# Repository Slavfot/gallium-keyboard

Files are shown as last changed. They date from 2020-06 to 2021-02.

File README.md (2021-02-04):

## Gallium Keyboard

The Gallium Keyboard is a Wireless Ergonomical Split Keyboard.

# DISCLAIMER

I have a problem with the keyboard that i have opened an issue at the redox Github. https://github.com/mattdibi/redox-keyboard/issues/55
The problem is interference making it hard to use in some environments.
I use it daily at work and it works really good except sometimes i have to replug the usb receiver at startup to get a good connection.
At home it is almost unusable because of interference. Missing key presses and high latency.
I'm trying to solve this and will post an update when i find a stable solution for the wireless communication.

# Future
At the moment I'm working on a micro pro version wich will make it possible to use the nice!nano bluetooth module with it instead.
My goal is to stock these and sell as kits togehter with 3D printed case. And even aluminium cases in GB.

## Summary

  - [Bill of materials](#bill-of-materials)
  - [Transmitters Assembly](#transmitters-assembly)
  - [Receiver Assembly](#receiver-assembly)
  - [Firmware](#firmware)
  - [Battery usage](#battery-usage)

## Bill of materials

#### Transmitters

| Qty | Item | Notes |
|----:|---|---|
|  62 | Cherry MX compatible switches | |
|  62 | Kailh MX hot swap sockets (optional) | |
| 2 | Gallium Wireless PCBs | |
| 2 | YJ-14015 modules (Core51822B clones) | [aliexpress or ebay](https://www.aliexpress.com/item/NRF51822-Core51822-BLE-4-0-Bluetooth-2-4G-Wireless-Module-Antenna-Board-For-ULP-SPI-I2C/32842154172.html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,searchweb201602_1_10065_10068_10843_10059_10884_10887_10696_100031_10084_10083_10103_10618_10304_10307_10820_10821_10302,searchweb201603_60,ppcSwitch_5&algo_expid=1dded059-5054-4890-bcc4-6face1150a21-1&algo_pvid=1dded059-5054-4890-bcc4-6face1150a21&priceBeautifyAB=0)
|  62 | 1N4148 diodes | SMD 1N4148 SOD-123 diodes can also be used |
| 2 | Keystone 3034 SMT battery holders | [digikey](https://www.digikey.com/product-detail/en/keystone-electronics/3034/36-3034-ND/4499289)|
| 2 | PCM12SMTR SMT slide switches | [digikey](https://www.digikey.com/product-detail/en/c-k/PCM12SMTR/401-2016-1-ND/1640125)|
| 2 | Right angle 0.1" header (1x4pin) | |

#### Receiver

| Qty | Item | Notes |
|----:|---|---|
| 1 | Redox receiver PCB | |
| 1 | YJ-14015 module (Core51822B clone) | [aliexpress or ebay](https://www.aliexpress.com/item/NRF51822-Core51822-BLE-4-0-Bluetooth-2-4G-Wireless-Module-Antenna-Board-For-ULP-SPI-I2C/32842154172.html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,searchweb201602_1_10065_10068_10843_10059_10884_10887_10696_100031_10084_10083_10103_10618_10304_10307_10820_10821_10302,searchweb201603_60,ppcSwitch_5&algo_expid=1dded059-5054-4890-bcc4-6face1150a21-1&algo_pvid=1dded059-5054-4890-bcc4-6face1150a21&priceBeautifyAB=0) |
| 1 | Arduino 5v 16MHz Pro Micro compatible microcontroller  | [aliexpress or ebay] |
| 1 | 1117 3.3v regulator in SOT223 | [digikey](https://www.digikey.com/product-detail/en/diodes-incorporated/AZ1117IH-3.3TRG1/AZ1117IH-3.3TRG1DICT-ND/5699682)|
| 2 | 330 Ohm 0805(2012 metric) SMD resistors | Default configuration. Values depends on LED color, see [below](#resistor-values)|
| 2 | 220 Ohm 0805(2012 metric) SMD resistors | Default configuration. Values depends on LED color, see [below](#resistor-values)|
| 3 | 1.5k Ohm 0805(2012 metric) SMD resistors | Default configuration. See [below](#resistor-values)|
| 1 | Red 0805(2012 metric) SMD standard LED | Default configuration. |
| 1 | Blue 0805(2012 metric) SMD standard LED | Default configuration. |
| 1 | Green 0805(2012 metric) SMD standard LED | Default configuration. |
| 1 | White 0805(2012 metric) SMD standard LED | Default configuration. |
| 1 | Through hole momentary switch | Dimensions 6mm x 6mm x 4.3mm |
| 1 | Right angle 0.1" header (1x4pin) | |
| 2 | Straight hot swap 0.1" header (1x6pin) | Use wire from diods as legs |

> :information_source: You can also use the [Mitosis receiver](https://github.com/reversebias/mitosis-hardware/blob/master/bom/README.md) since it's almost identical, or you can build a receiver on your own. 

> :warning: To program the YJ-14015 MCUs you need an ST-Link v2 programmer, these can be found on eBay or Aliexpress for as little as 2$ shipped. See [picture below](#nordic-mcus-firmware).

##### Resistor values

If you want to customize your LEDs color or save a few bucks by ordering the LED all the same color you can refer to this section for choosing the correct resistor values. Otherwise you can refer to the [default configuration](#default-configuration).

There are two sets of resistor that you need for the receiver.

- The voltage divider resistors (`R1`, `R2` and `R3`): anything between 1.5k Ohm and 4.7k Ohm is good.
- The LEDs resistors (`R4`,`R6`,`R7` and `R8`): see the following table.

| LED color | Vf | Suggested resistor value |
|---|---|---|
| Red | 1.7V | 330 Ohm |
| Yellow | 2.1V | 330 Ohm |
| Blue | 3.2V | 220 Ohm |
| Green | 2.2V | 330 Ohm |
| White | 3.6V | 220 Ohm |

Depending on the color you choose to use you should use the resistor listed above.

#### Default configuration

Here you can find the default configuration for the receiver assembly.

| Label | Component |
|---|---|
| D1 | Red LED |
| D2 | Blue LED |
| D3 | Green LED |
| D4 | White LED |
| R4 |  330 Ohm resistor |
| R6 |  220 Ohm resistor |
| R7 |  330 Ohm resistor |
| R8 |  220 Ohm resistor |
| R1 | 1.5k Ohm resistor |
| R2 | 1.5k Ohm resistor |
| R3 | 1.5k Ohm resistor |

## Transmitters Assembly

<p align="center">
Wireless gallium PCBs
</p>

Assembly steps:

- Solder components to PCBs.
  1. Solder slider switch. 
  2. Solder the YJ-14015 on the same side as the slider switch.
  3. Solder 1N4148 diodes either SMT or THT (Surface-mount Technology or Through-hole Technology).
  4. Apply insulating tape over the pads surrounding the battery ground pad before soldering the battery holder [picture below](#battery-holder-installation-detail).
  5. Some solder is needed on the ground pad to contact properly with the battery. See [picture below](#battery-holder-installation-detail).
  6. Solder the battery holders.
  7. If you use the onboard CR2032 battery holder then bridge the jumper JP_BAT1 to either R or L depending on wich side the battery is located on. See [picture below](#bridge-jumper).
     (This is not needed if you use external battery pinout EXT-BAT)
  8. Solder the programming headers.
  9. (Optional) Solder Kailh Hot Swap Sockets
- Fit the PCBs inside their cases.
- Add the switches to the plate.
- Solder switches to the PCB.
- Add the CR2032 batteries.
- Program the MCUs.
- Close the case.

##### How i solder surface mount components:
Wet one pad with solder.
Position the component and hold the component in place with a tweezer.
Heat up the wet pad and let cool, this should fix the component.
Re-heat and adjust the position if the component isn't placed perfect.
Be sure not to heat to long wich may damage the PCB or the component.
Solder the rest of the pads like normal.

##### Programming headers detail:

<p align="center">
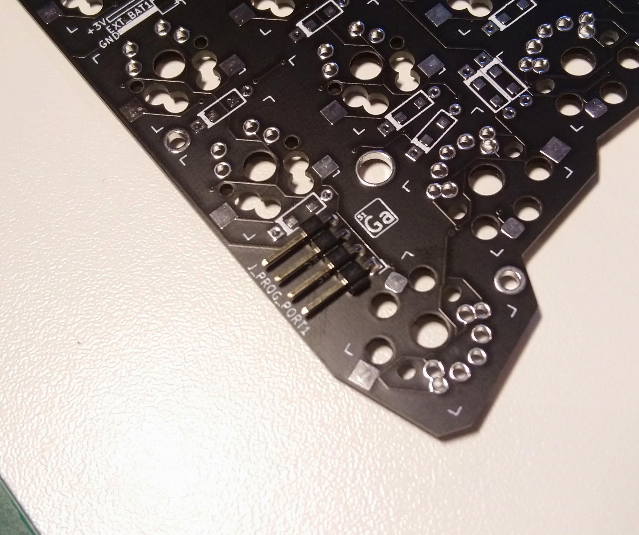
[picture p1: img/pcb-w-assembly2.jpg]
Programming headers detail

</p>

##### MCUs detail:

<p align="center">
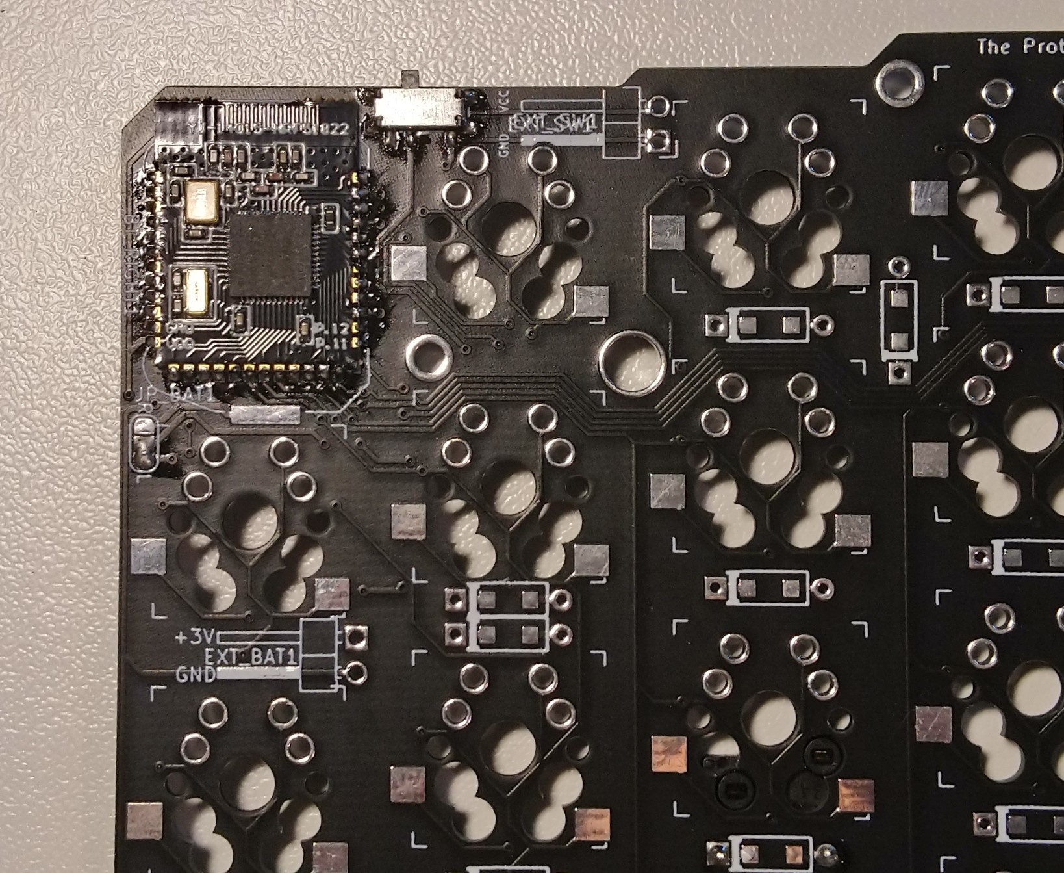
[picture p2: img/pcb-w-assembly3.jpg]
MCUs detail

</p>

##### Slider switch detail:

<p align="center">
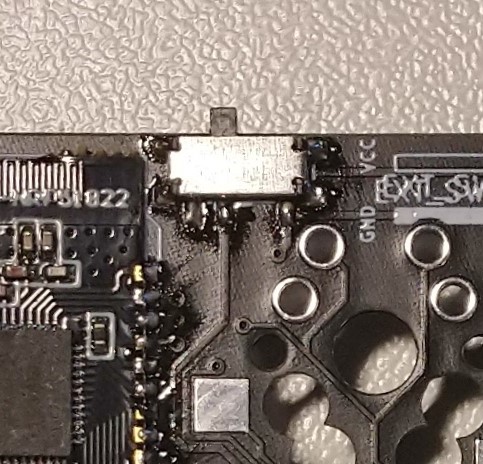
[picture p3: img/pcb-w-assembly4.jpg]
Slider switch detail

</p>

##### Diodes installation detail:

<p align="center">
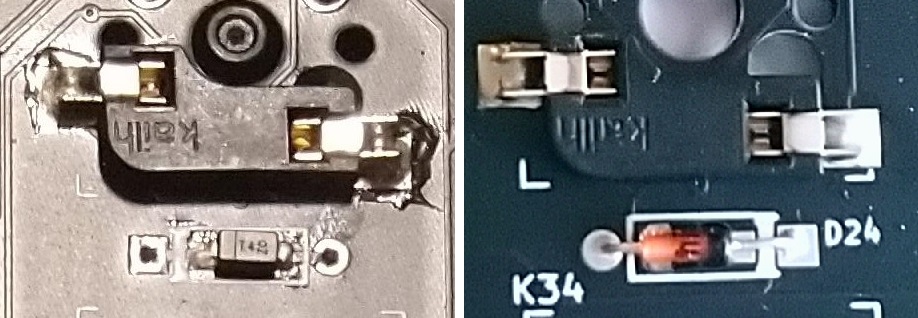
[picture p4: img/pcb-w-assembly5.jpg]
Diode installation detail

</p>
SMT on the left and THT on the right.

##### Battery holder installation detail:

<p align="center">
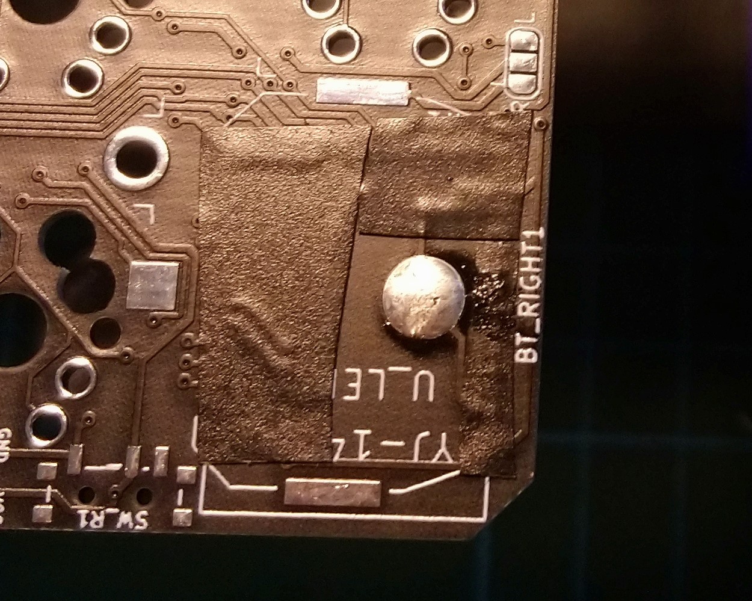
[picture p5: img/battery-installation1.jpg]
Battery holder installation detail. Ground pad.

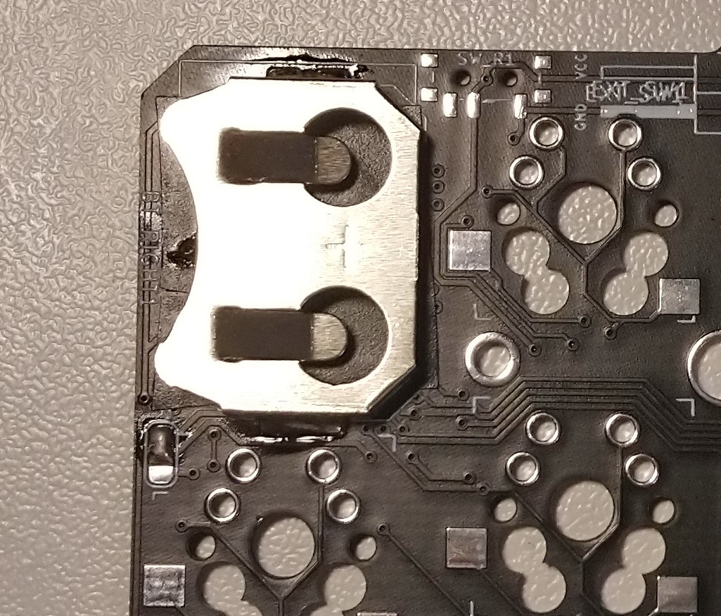
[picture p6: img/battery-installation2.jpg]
Battery holder installation detail. Assembled.

</p>

##### Left and right hand completed assembly:

<p align="center">
Left and right hand completed assembly
</p>

##### Assembled PCB:

<p align="center">
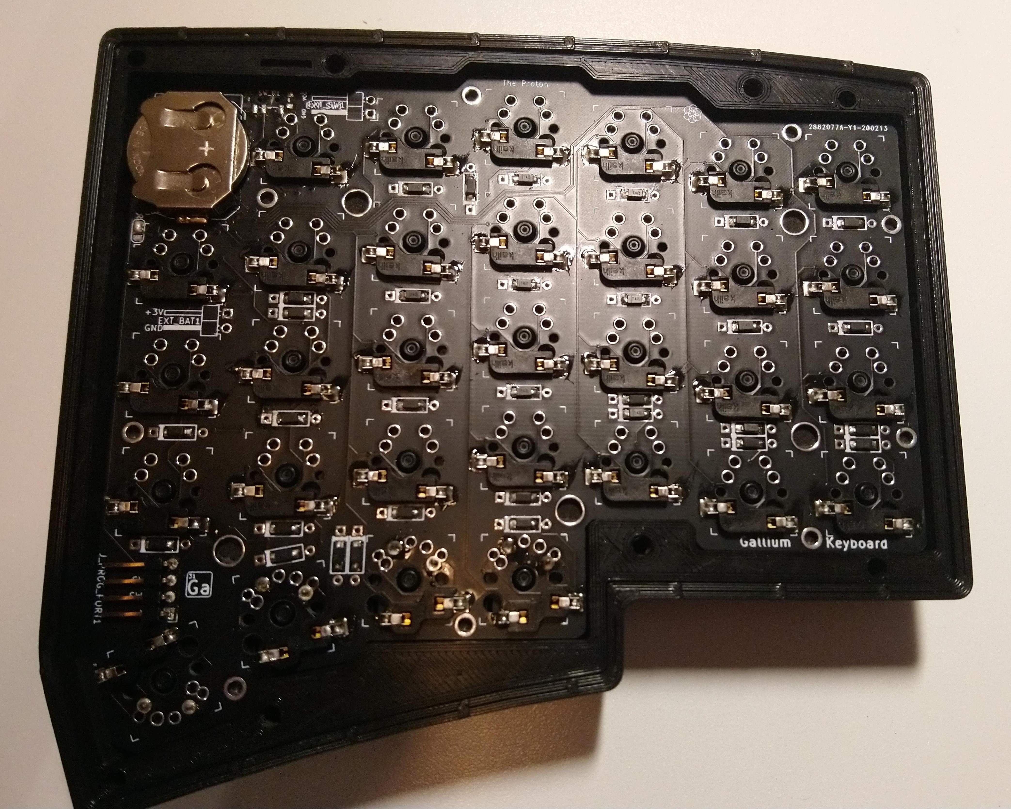
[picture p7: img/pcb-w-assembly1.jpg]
Wireless Redox assembled PCB

</p>

## Receiver Assembly

The receiver assembly is pretty straightforward i suggest soldering it in this order:

1. Solder D1, D2, D3 and D4 LEDs. See [image](#leds-installation-detail) for orientation.
2. Solder R4, R6, R7 and R8 resistors.
3. Solder R1, R2 and R3 resistors.
4. Solder the AMS1117.
5. Solder the programming headers. I suggest you to cut the excess of the header **before** soldering the headers. You should stay as flush to the PCB surface as possible since the controller will be soldered above the headers. Use some masking tape to help you keep the header in place while soldering.
6. Solder the Arduino Pro Micro headers.
7. Solder the YJ-14015. I suggest you to glue it in place or use some masking tape to help you during soldering.
8. Solder the reset button.
9. Upload the firmware and you're done.

##### Assembled PCB, front:

<p align="center">
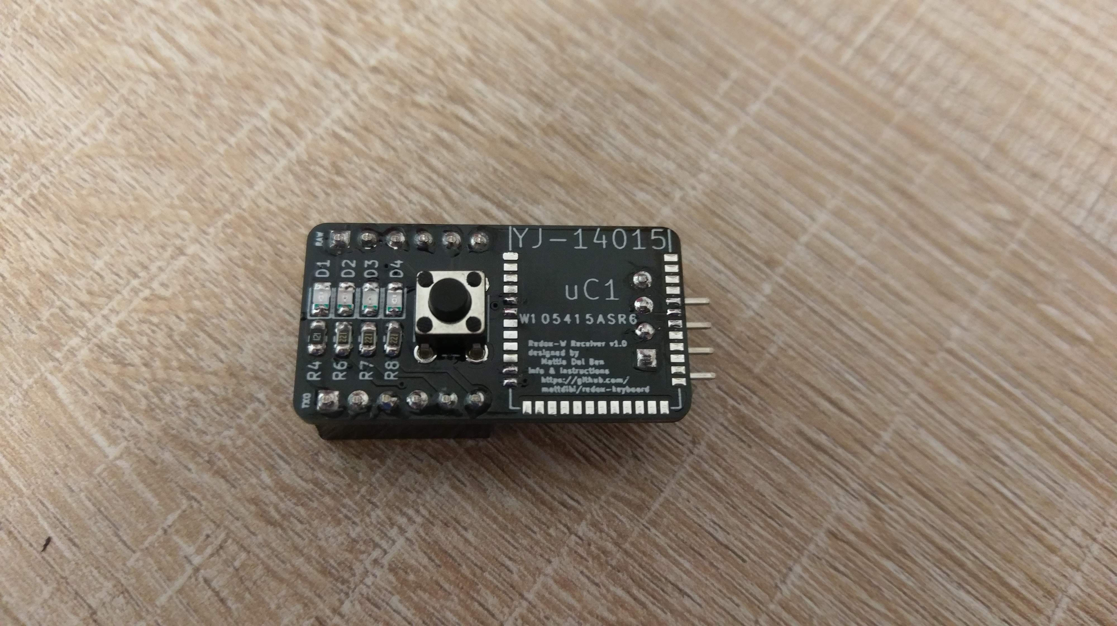
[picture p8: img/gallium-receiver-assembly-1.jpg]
Assembled receiver PCB, front.

</p>

##### Assembled PCB, back:

<p align="center">
Assembled receiver PCB, back.
</p>

##### LEDs installation detail:

<p align="center">
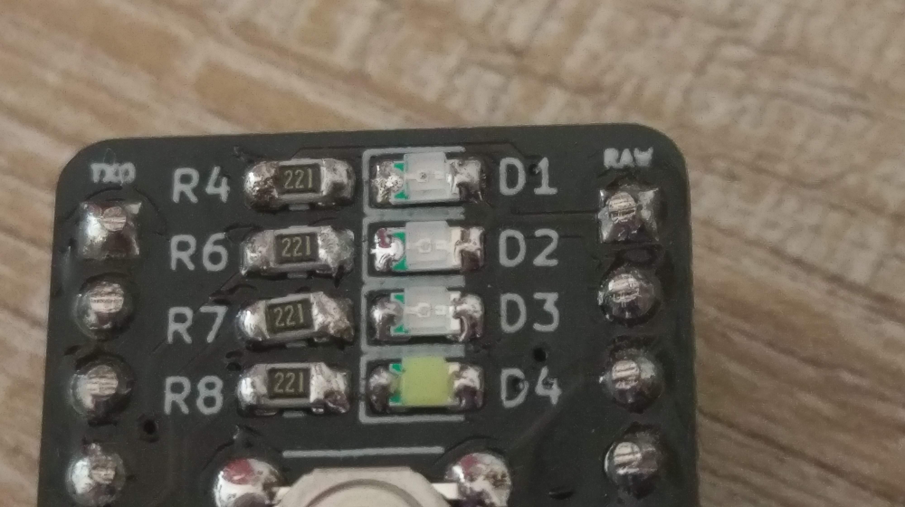
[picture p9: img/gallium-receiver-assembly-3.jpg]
Assembled receiver PCB, LEDs installation detail.

</p>

> :information_source: Please note that here I installed 220 Ohm resistors because I used only blue and white LEDs as I only had those laying around. You should use the resistor values suggested [here](#resistor-values) or follow the [default configuration](#default-configuration).

## Firmware

**Basics**: The Gallium keyboard works similarly to the [Mitosis keyboard](https://github.com/qmk/qmk_firmware/tree/master/keyboards/mitosis): we have two transmitters responsible for scanning the two matrices, which then transmit the matrix status through the [Gazel protocol](https://developer.nordicsemi.com/nRF5_SDK/nRF51_SDK_v5.x.x/doc/5.2.0/html/a00140.html) to the receiver. The receiver is another YJ-14015 which receives the two matrix scans and send it through serial to the Arduino Pro Micro. The Pro Micro is responsible for running QMK and converting the bytes received by the YJ-14015 into actual keystrokes.

Firmware sources available here: [https://github.com/slavfot/gallium-firmware](https://github.com/slavfot/gallium-firmware).

You'll need to upload the firmware to the corresponding MCUs as per the following diagram:

<p align="center">
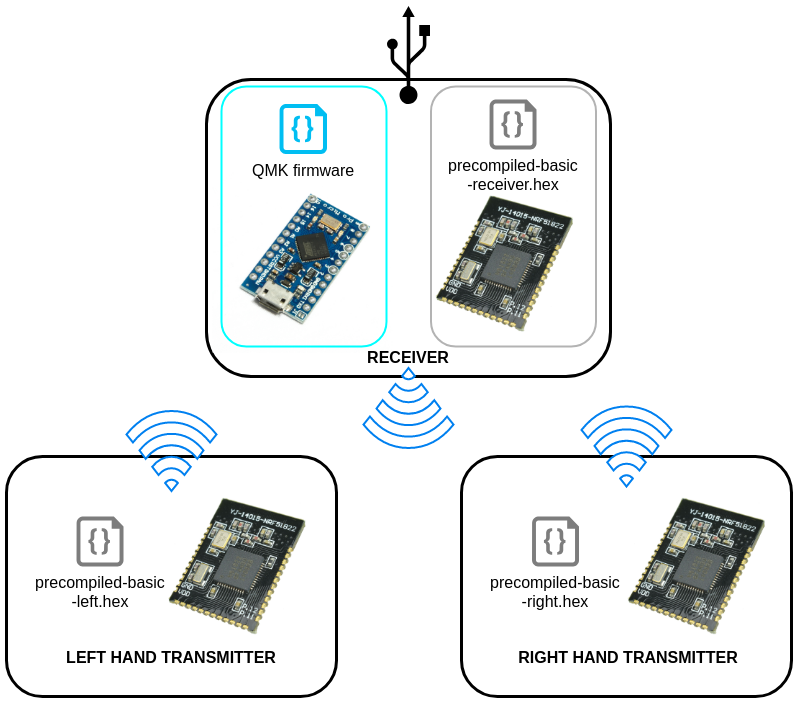
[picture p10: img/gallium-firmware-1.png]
Gallium firmware diagram.

</p>

Note that you'll need to upload the firmware for the YJ-14015 only once. Everything related to the keymap is handled by the Arduino Pro Micro and QMK Firmware, that's what you will need to modify to update the keymap.

### Step-by-step firmware upload guide

#### Arduino Pro Micro Firmware upload

Let's start by uploading the QMK firmware on the Arduino, this will help us in diagnosing problems early on. The Gallium uses QMK for its firmware, follow the QMK installation instructions [here](https://docs.qmk.fm/#/getting_started_build_tools), then compile and burn the firmware as follows:

```sh
$ cd path/to/qmk_firmware
$ make gallium:default:avrdude
```

You can find the code for the Gallium here: [QMK - Gallium Wireless keyboard](https://github.com/slavfot/qmk_firmware/tree/gallium/keyboards/gallium).

In the [Gallium Keyboard firmware repository](https://github.com/slavfot/gallium-firmware/tree/master/precompiled) I added some pre-built hex files with the default keymap for testing purpose.

#### Nordic MCUs Firmware upload

You'll need only to flash the pre-built `.hex` files to the corresponding MCUs, for this you'll need an STLinkV2 debugger.

<p align="center">
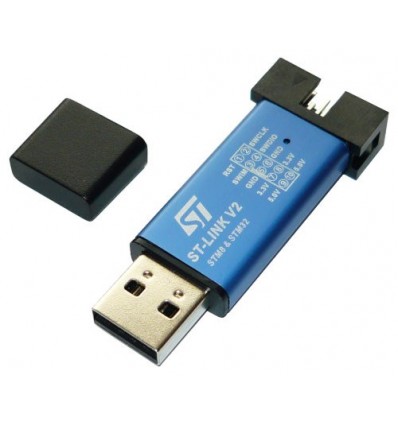
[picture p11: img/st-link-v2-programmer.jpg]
ST-Link v2 programmer

</p>

# Flashing firmware with Windows

## Setup the environment

##### 1. Activate Telnet Client in windows:

- Open the Control Panel - with View By: Category.
- Click on Programs.
- Click on Turn Windows features on or off.
- Click on the checkbox next to Telnet client.
- Click OK.

##### 2. Download pre-compiled openOCD
https://freddiechopin.info/en/download/category/4-openocd <br>
Unzip anywhere. 
But for ease of use in CMD i put it in C:\OpenOCD

## Flash with CMD

###### 1. Hook up the receiver/keyboard half

Hook up the ST-Link debugger to the receiver/keyboard board you assembled without the Arduino. You need to connect only the `VCC`, `GND`, `SWDIO` and `SWCLK` pins of the board like this:

| ST-Link Debugger | Receiver board |
|---|---|
| 3.3V | VCC |
| GND | GND |
| SWCLK | SWCLK |
| SWDIO | SWDIO |

<p align="center">
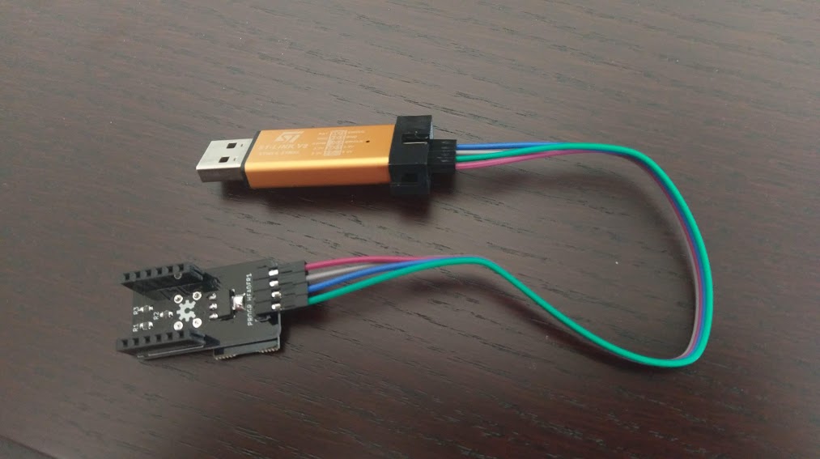
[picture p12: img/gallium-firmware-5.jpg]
ST-Link debugger wiring.

</p>

Then plug in the ST-Link debugger into your PC.

##### 2. Launch CMD.

##### 3. With terminal commands position the CMD in 
```
\openOCD\bin
```
First make sure you are in the right drive.
If you need to change drive then type the drive letter only likes this "d:" <br>
after that you can navigate in that drive.

Commands to navigate with:

- cd (change directory)
- cd .. (go back one directory)
- dir (show all the directorys in the folder you are located in)

Tips: Press the tab button to automaticaly complete the directorys name while typing the cd command.

##### 4. Download Gallium-keyboard repository
Download Gallium-keyboard master zip and unzip anywhere but for ease of use put it in C:\
https://github.com/Slavfot/gallium-keyboard/archive/master.zip

##### 5. Launch CMD
Launch an openOCD server session with this command:

```sh
openocd -s C:\OpenOCD\scripts\ -f interface/stlink-v2.cfg -f target/nrf51.cfg
```

This line is written as if the OpenOCD folder is located at C:\ <br>
Change accordingly to where you have it located.

It should give you an output ending in:

```
Info : nrf51.cpu: hardware has 4 breakpoints, 2 watchpoints
```
Otherwise you likely have a loose or wrong wire.

##### 6. Launch another CMD window.

##### 7. cd to the location where the hex is located.

Example for the file path if the .hex file is located in C:\Gallium-keyboard\precompiled

/gallium-keyboard/precompiled/

##### 8. Run these commands in the new window, wait for each command to finish until you run the next command.
Connect to the OpenOCD session:
```
telnet localhost 4444
```
From the factory, these chips need to be erased:
```sh
reset halt

nrf51 mass_erase
```
Write file to wireless-module

Use this command to flash the receiver:
```sh
flash write_image /gallium-keyboard/precompiled/precompiled-basic-receiver.hex
```
For each keyboard half flash with either of these files
```sh
flash write_image /gallium-keyboard/precompiled/precompiled-basic-left.hex
```
or
```sh
flash write_image /gallium-keyboard/precompiled/precompiled-basic-right.hex
```

This is how it should look when you connect to telnet:

<p align="center">
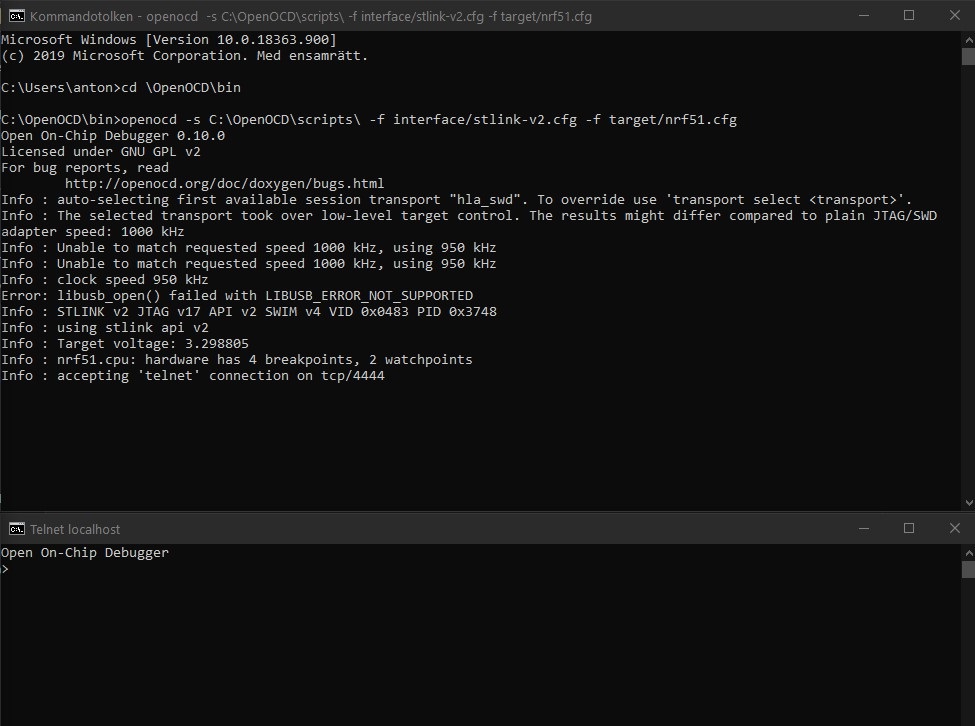
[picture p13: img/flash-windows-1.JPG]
flashing-on-windows-1

</p>

The whole process should look like this:

<p align="center">
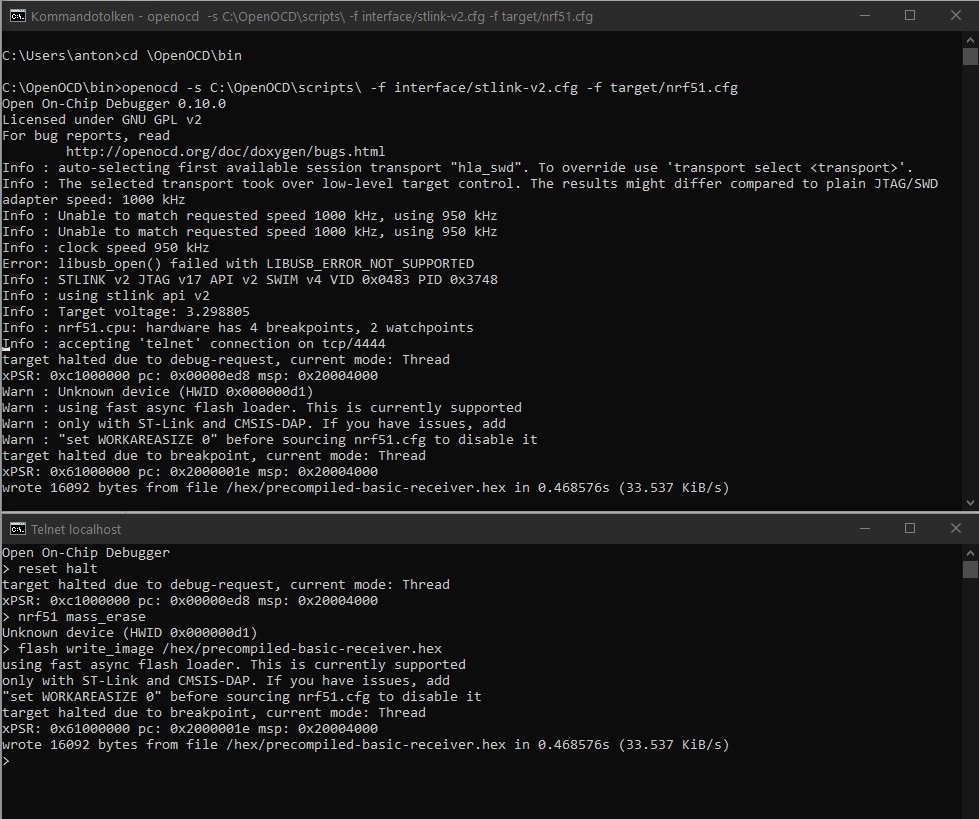
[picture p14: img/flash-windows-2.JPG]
flashing-on-windows-2

</p>

##### 9. Repeat untill you have flashed all three wireless modules.

##### 10. End openOCD sessionen with ctrl+C in the first CMD window.
Congratulations you have now flashed your Gallium Keyboard!

# Firmware upload using Linux

*Note*: Tested on Ubuntu 16.04 and 18.04 but you should be able to find alternatives on all distros.

##### Setup

###### Install OpenOCD (Open On-Chip Debugger)

```sh
sudo apt update
sudo apt install openocd
```

###### Download the repository

Open a terminal and download this repository wherever you want. We'll need the `gallium/firmware` folder content.

```sh
git clone https://github.com/slavfot/gallium-keyboard.git
```

or

```sh
wget https://github.com/slavfot/gallium-keyboard/archive/master.zip
```

###### Install the udev rules

```sh
cd path/to/repository/gallium-keyboard/firmware/
sudo cp 49-stlinkv2.rules /etc/udev/rules.d/
```

##### Programming the wireless modules Using Linux

###### Hook up the receiver/keyboard half

Hook up the ST-Link debugger to the receiver/keyboard board you assembled without the Arduino. You need to connect only the `VCC`, `GND`, `SWDIO` and `SWCLK` pins of the board like this:

| ST-Link Debugger | Receiver board |
|---|---|
| 3.3V | VCC |
| GND | GND |
| SWCLK | SWCLK |
| SWDIO | SWDIO |

<p align="center">
ST-Link debugger wiring.
</p>

Then plug in the ST-Link debugger into your PC.

###### Launch an OpenOCD server session

In a new terminal window launch an OpenOCD server session by issuing the following command:

```sh
openocd -s /usr/local/Cellar/open-ocd/0.8.0/share/openocd/scripts/ -f interface/stlink-v2.cfg -f target/nrf51.cfg
```

This should give the following output:

```sh
Info : nrf51.cpu: hardware has 4 breakpoints, 2 watchpoints
```

Leave this terminal window open.

###### Wireless-module firmware flashing

There are three Wireless modules that need to be flashed with firmware:
The receiver, left hand keyboard hand the right hand keyboard.

We can now issue the flashing commands. Open a terminal in the Gallium firmware folder.

```sh
cd path/to/repository/gallium-keyboard/firmware/
```

From the factory, these chips need to be erased:

```sh
echo reset halt | telnet localhost 4444
echo nrf51 mass_erase | telnet localhost 4444
```

You should be seeing some movement in the OpenOCD terminal window, and you desktop should be looking somewhat like this:

<p align="center">
Receiver firmware flashing.
</p>

Now we can upload the receiver firmware onto the MCU.

```sh
echo reset halt | telnet localhost 4444

!Choose one!:
receiver:
echo flash write_image `readlink -f precompiled-basic-receiver.hex` | telnet localhost 4444

Left hand keyboard:
echo flash write_image `readlink -f precompiled-basic-left.hex` | telnet localhost 4444

Right hand keyboard:
echo flash write_image `readlink -f precompiled-basic-right.hex` | telnet localhost 4444

and last:
echo reset | telnet localhost 4444
```

You should be looking at something like this:

<p align="center">
Receiver firmware flashing.
</p>

Now close the OpenOCD session (use `Ctrl-C`) and you're done with the flashing. Repeat these steps for all three modules.

When all three modules have been flash you are done!
Congratulations, You flashed the Gallium Keyboard!

## Battery usage

mattdibi about the battery consumption:

With a CR2032 with 220mAh we can expect **at least 880 hours** of continuous typing on the keyboard before needing to change the batteries. Keep in mind that when you're not typing (500ms without key presses is the time interval needed for the keyboard) the transmitters go into deep sleep mode and draw only 2.7uA. So for an everyday use (4 hours a day of continuous typing) you can expect a battery life of at least a year. Obviously your mileage may vary.
Source and calculations: https://github.com/mattdibi/redox-keyboard/tree/master/redox-w#battery-usage

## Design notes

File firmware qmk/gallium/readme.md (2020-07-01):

Gallium Wireless Keyboard
=======

<p align="center">
Gallium PCB
</p>

More information and building instruction [here](https://github.com/slavfot/gallium-keyboard).

- Keyboard Maintainer: [@slavfot](https://github.com/slavfot)  
- Hardware Supported: Gallium PCB  
- Hardware Availability: Slavfot

Make example for this keyboard (after setting up your build environment):

```sh
make gallium:default
```

Example of flashing this keyboard:

```sh
make gallium:default:avrdude
```

See the [build environment setup](https://docs.qmk.fm/#/getting_started_build_tools) and the [make instructions](https://docs.qmk.fm/#/getting_started_make_guide) for more information. Brand new to QMK? Start with our [Complete Newbs Guide](https://docs.qmk.fm/#/newbs).

For nRF51822 firmware upload instruction and development see [the Gallium wireless firmware repository](https://github.com/slavfot/gallium-firmware).

## Gallium Notes

These configuration files were based off the [redox-w](https://github.com/qmk/qmk_firmware/tree/master/keyboards/redox_w), [Mitosis](https://github.com/qmk/qmk_firmware/tree/master/keyboards/mitosis) and [Atreus](https://github.com/technomancy/atreus) keyboard. It assumes a Pro Micro is being used, however retains the 'make upload' feature from the Atreus branch. This keyboard uses a completely different 'matrix scan' system to other keyboards, it relies on an external nRF51822 microcontroller maintaining a matrix of keystates received from the keyboard halves. The matrix.c file contains the code to poll the external microcontroller for the key matrix. As long as this file is not changed, all other QMK features are supported.

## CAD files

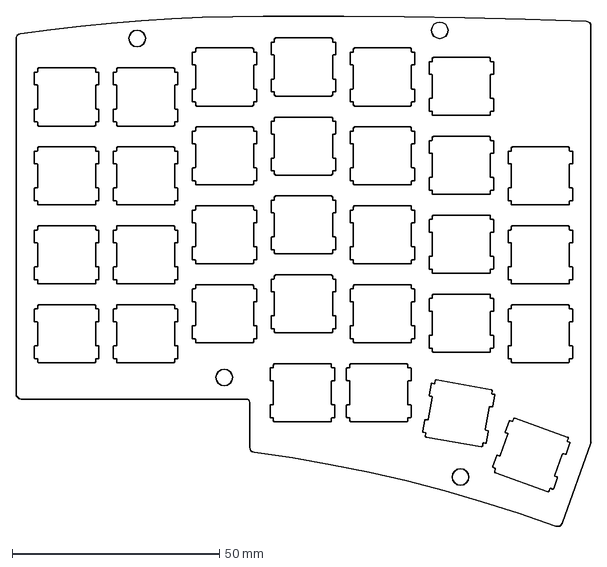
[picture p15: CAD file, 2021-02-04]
case/0.1/Gallium keyboard 0.1 Plate.DXF
138.8 x 123.1 mm

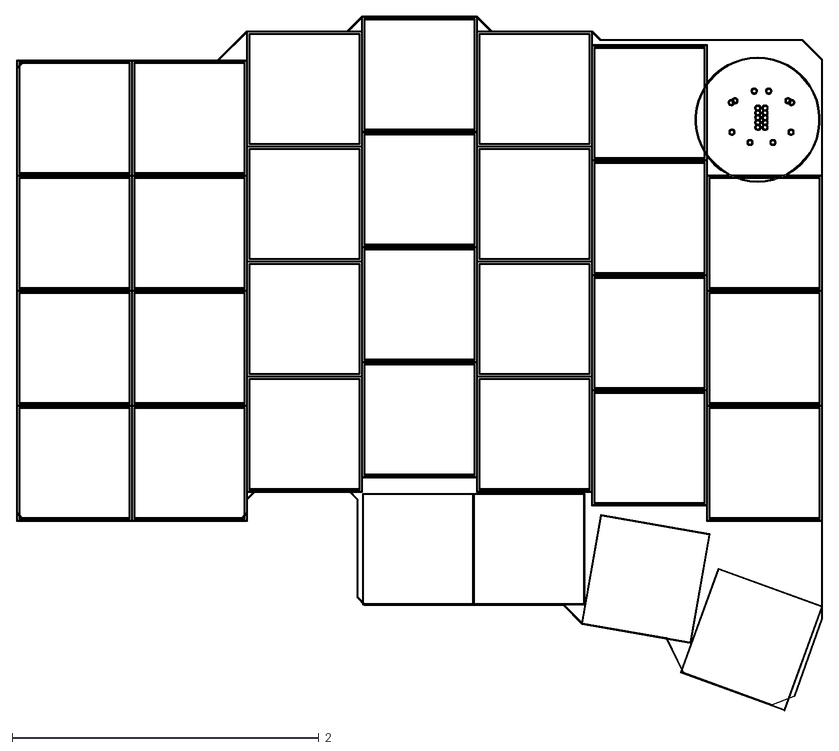
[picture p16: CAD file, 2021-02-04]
Kicad Files/0.1/Nukleon Keyboard-Dwgs_User.dxf
5.26 x 4.53

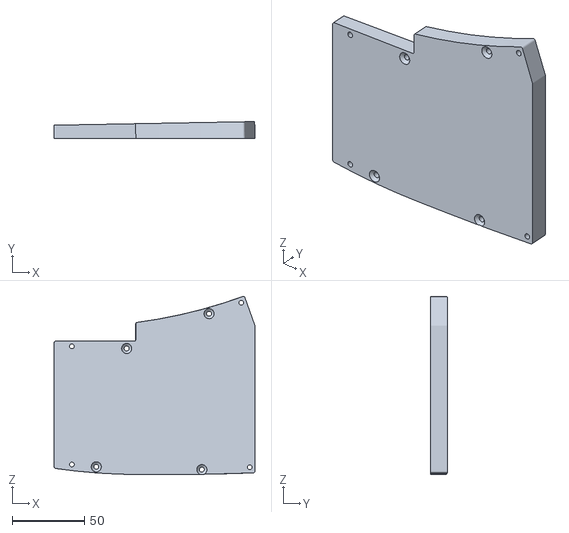
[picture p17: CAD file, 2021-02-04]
case/0.1/Gallium 0.1 Case Backplate+Inner Frame combined.STL
138.9 x 11.7 x 123.1

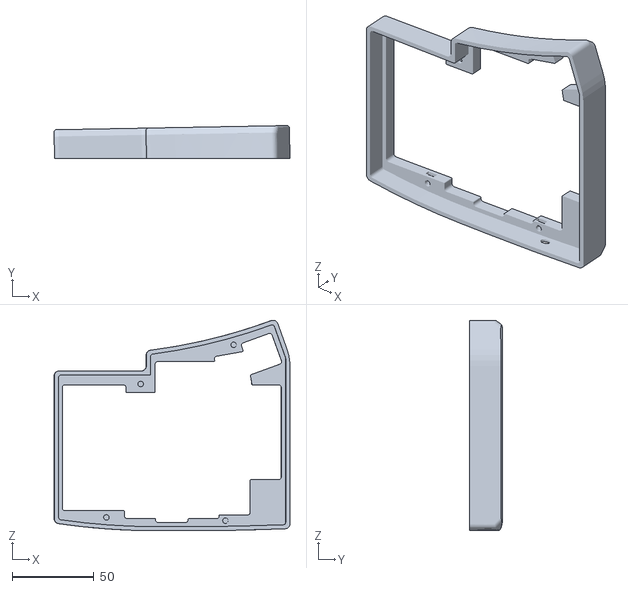
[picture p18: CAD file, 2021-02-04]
case/0.1/Gallium 0.1 Case Top.STL
144.7 x 20.2 x 129.0

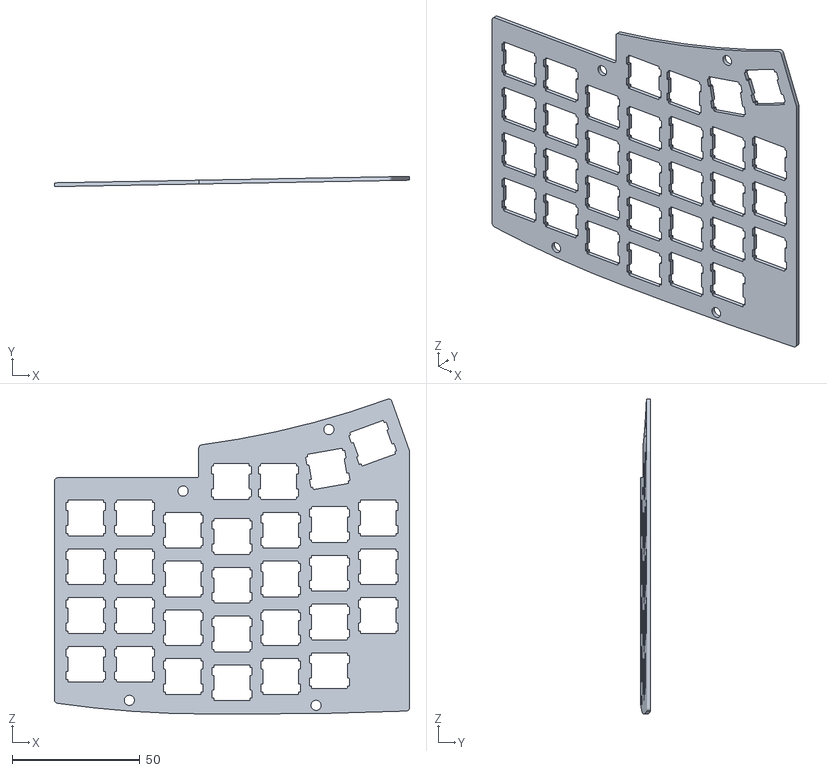
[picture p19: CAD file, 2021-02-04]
case/0.1/Gallium 0.1 Case Plate.STL
138.8 x 4.01 x 123.1

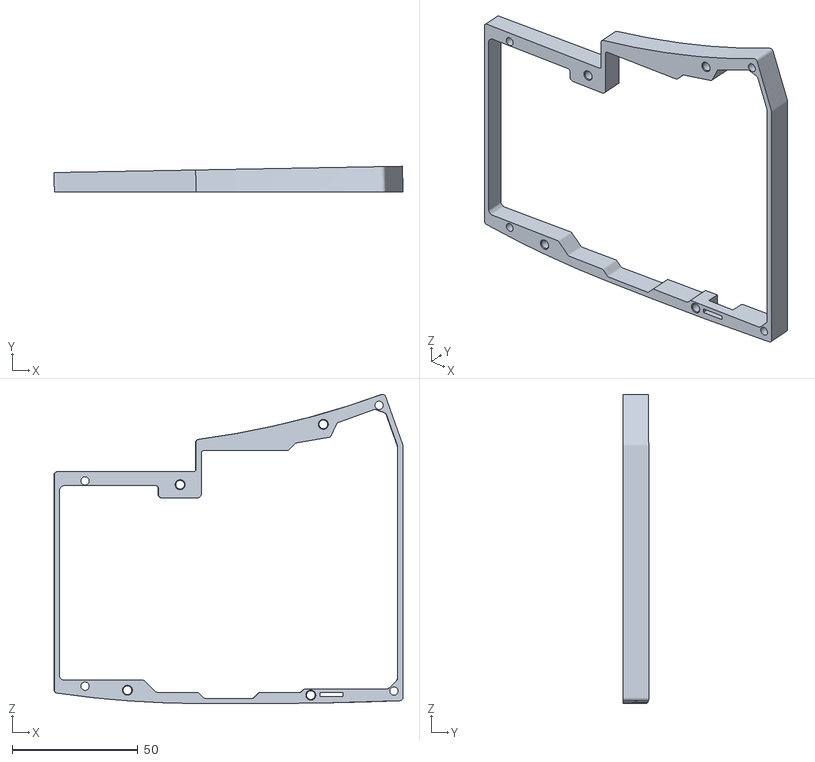
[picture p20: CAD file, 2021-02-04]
case/0.1/Gallium 0.1 Case Inner Frame.STL
138.9 x 10.2 x 123.1

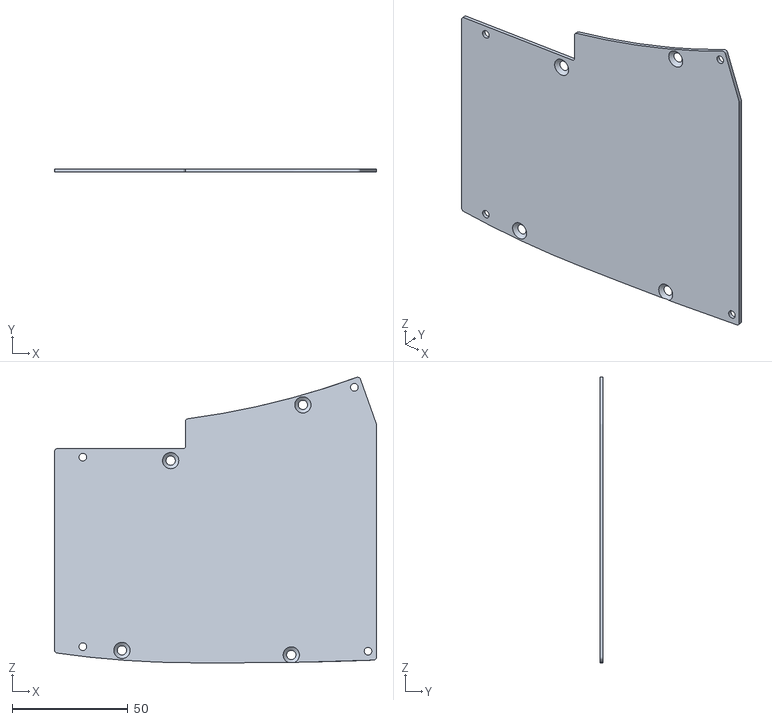
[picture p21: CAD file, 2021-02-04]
case/0.1/Gallium 0.1 Case Backplate .STL
138.8 x 1.50 x 123.1

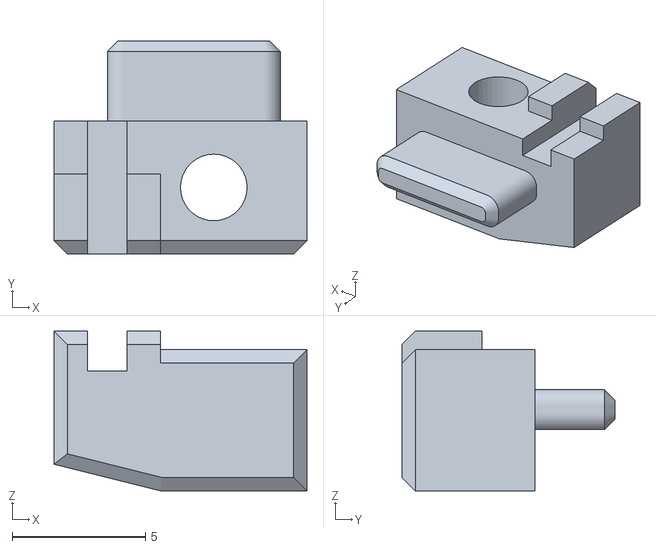
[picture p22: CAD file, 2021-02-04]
case/0.1/Gallium 0.1 Case Slider.STL
9.50 x 8.00 x 6.00

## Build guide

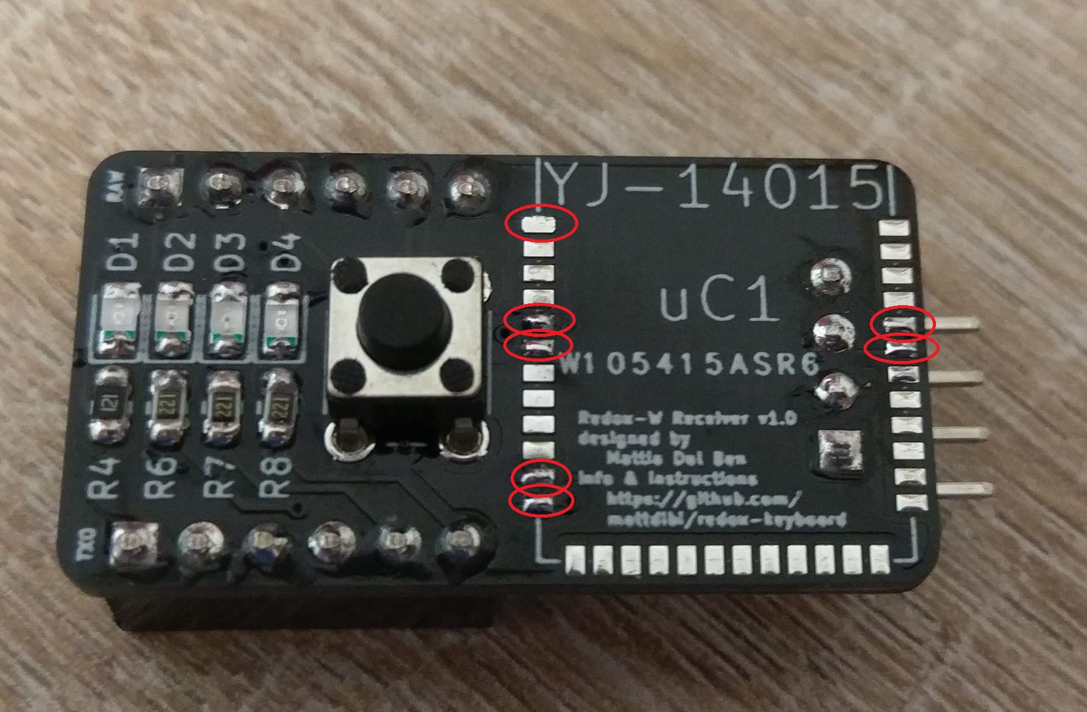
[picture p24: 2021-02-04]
img/gallium-receiver-assembly-4.jpg

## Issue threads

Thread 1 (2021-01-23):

Add PCB .kicad and Plate .svg?

walterhanley, 2021-01-23:
Hey! I really like this keyboard layout, and it accomplishes a lot of what I was looking to do in a Redox modification I was plotting (especially in terms of eliminating the 1.25u left and right mods for keycap compatibility). Would you be able to post the .kicad files you used to generate the PCB? I'm very interested in building my own (and maybe even designing another type of case). Would you be willing to do that? Doesn't need to be clean--I'd be appreciative either way.

Slavfot, 2021-01-28:
Hi!
I can upload everything.
But i have a problem with the keyboard that i have opened an issue at the redox Github. [https://github.com/mattdibi/redox-keyboard/issues/55](url)
The problem is interference making it hard to use in some environments.
I just it daily at my work and it works really good except that i sometimes have to replug the usb receiver at startup to get a good connection.
At home it is almost unusable because of interference. Missing key presses and high latency.

Slavfot, 2021-02-04:
I have uploaded kicad files, case .stl files and a .dxf of the plate.

walterhanley, 2021-02-05:
Thanks so much! I really appreciate it. And duly noted on the interference issues--I'll keep that in mind!

Closed 2021-02-05.

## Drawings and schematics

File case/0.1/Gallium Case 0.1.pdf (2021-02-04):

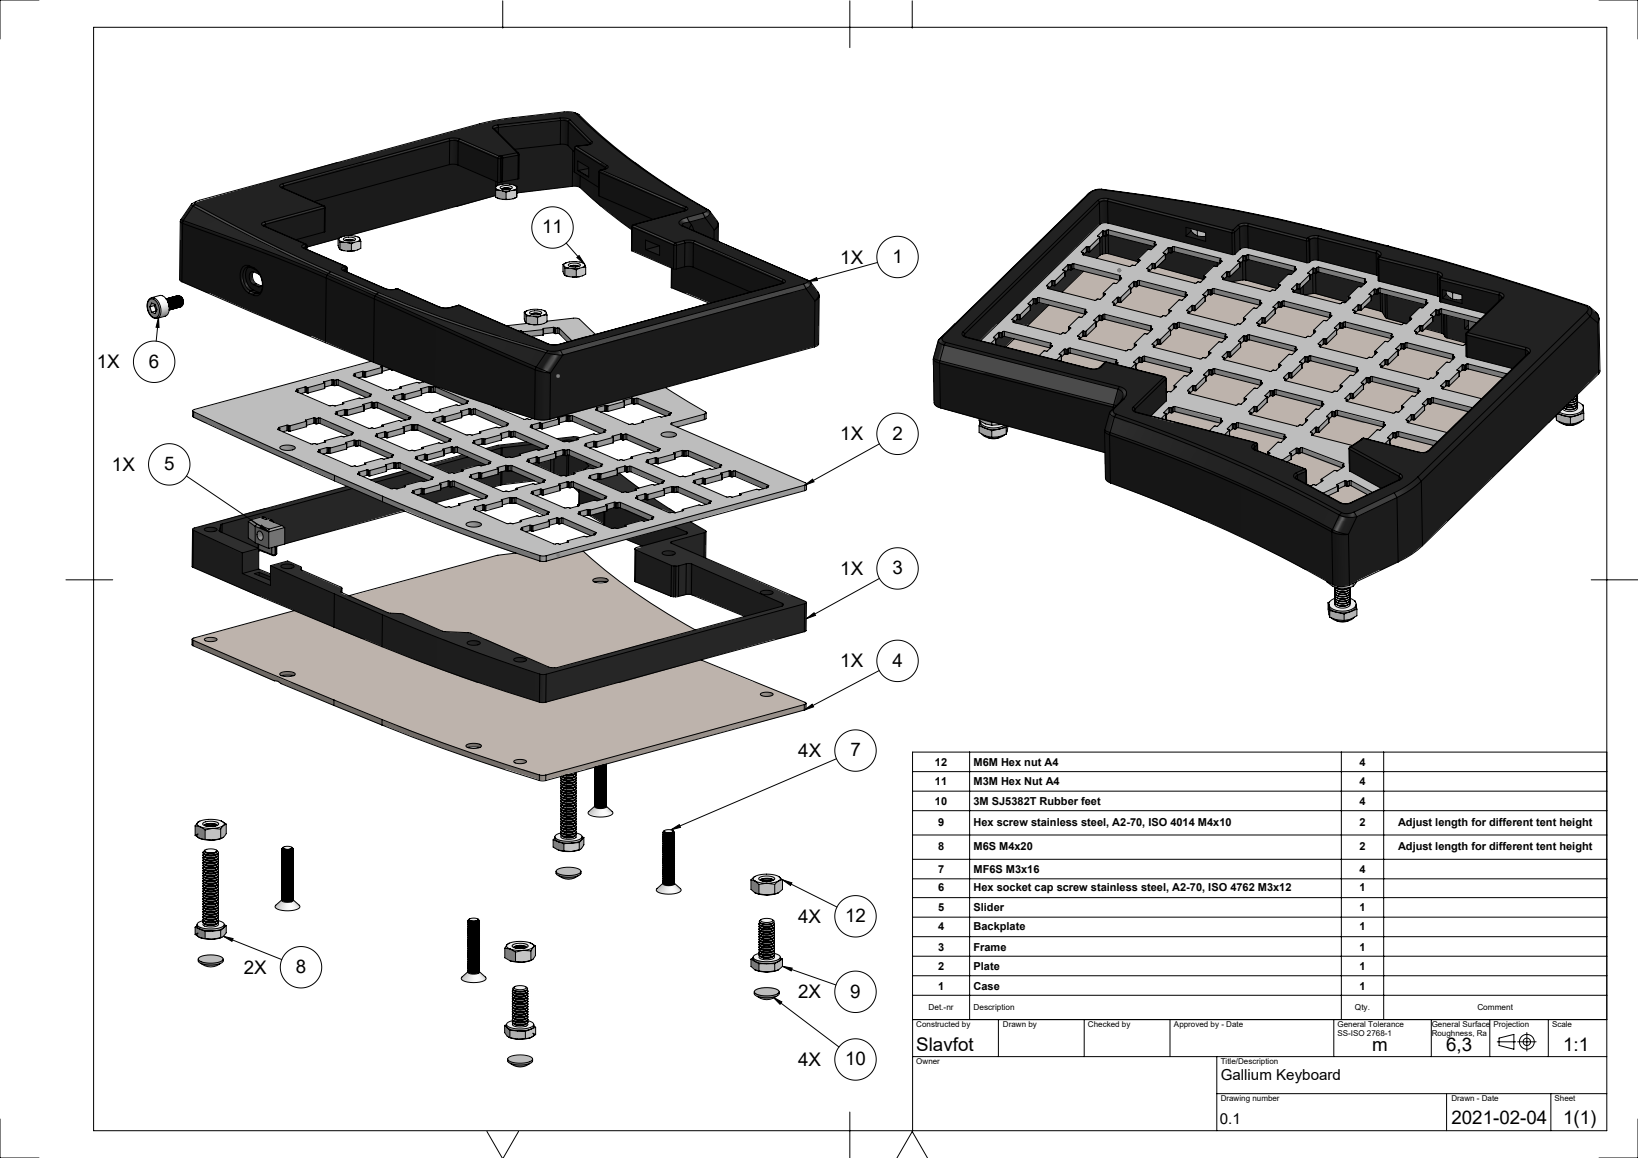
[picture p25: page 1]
Gallium Keyboard; Drawn - Date; General Surface; Scale; Roughness, Ra; Checked by; Approved by - Date; General Tolerance; Projection; SS-ISO 2768-1; Drawing number; Sheet; Drawn by; Constructed by

12 | M6M Hex nut A4 | 4
11 | M3M Hex Nut A4 | 4
10 | 3M SJ5382T Rubber feet | 4
9 | Hex screw stainless steel, A2-70, ISO 4014 M4x10 | 2 | Adjust length for different tent height
8 | M6S M4x20 | 2 | Adjust length for different tent height
7 | MF6S M3x16 | 4
6 | Hex socket cap screw stainless steel, A2-70, ISO 4762 M3x12 | 1
5 | Slider | 1
4 | Backplate | 1
3 | Frame | 1
2 | Plate | 1
1 | Case | 1

Det.-nr | Description | Qty. | Comment

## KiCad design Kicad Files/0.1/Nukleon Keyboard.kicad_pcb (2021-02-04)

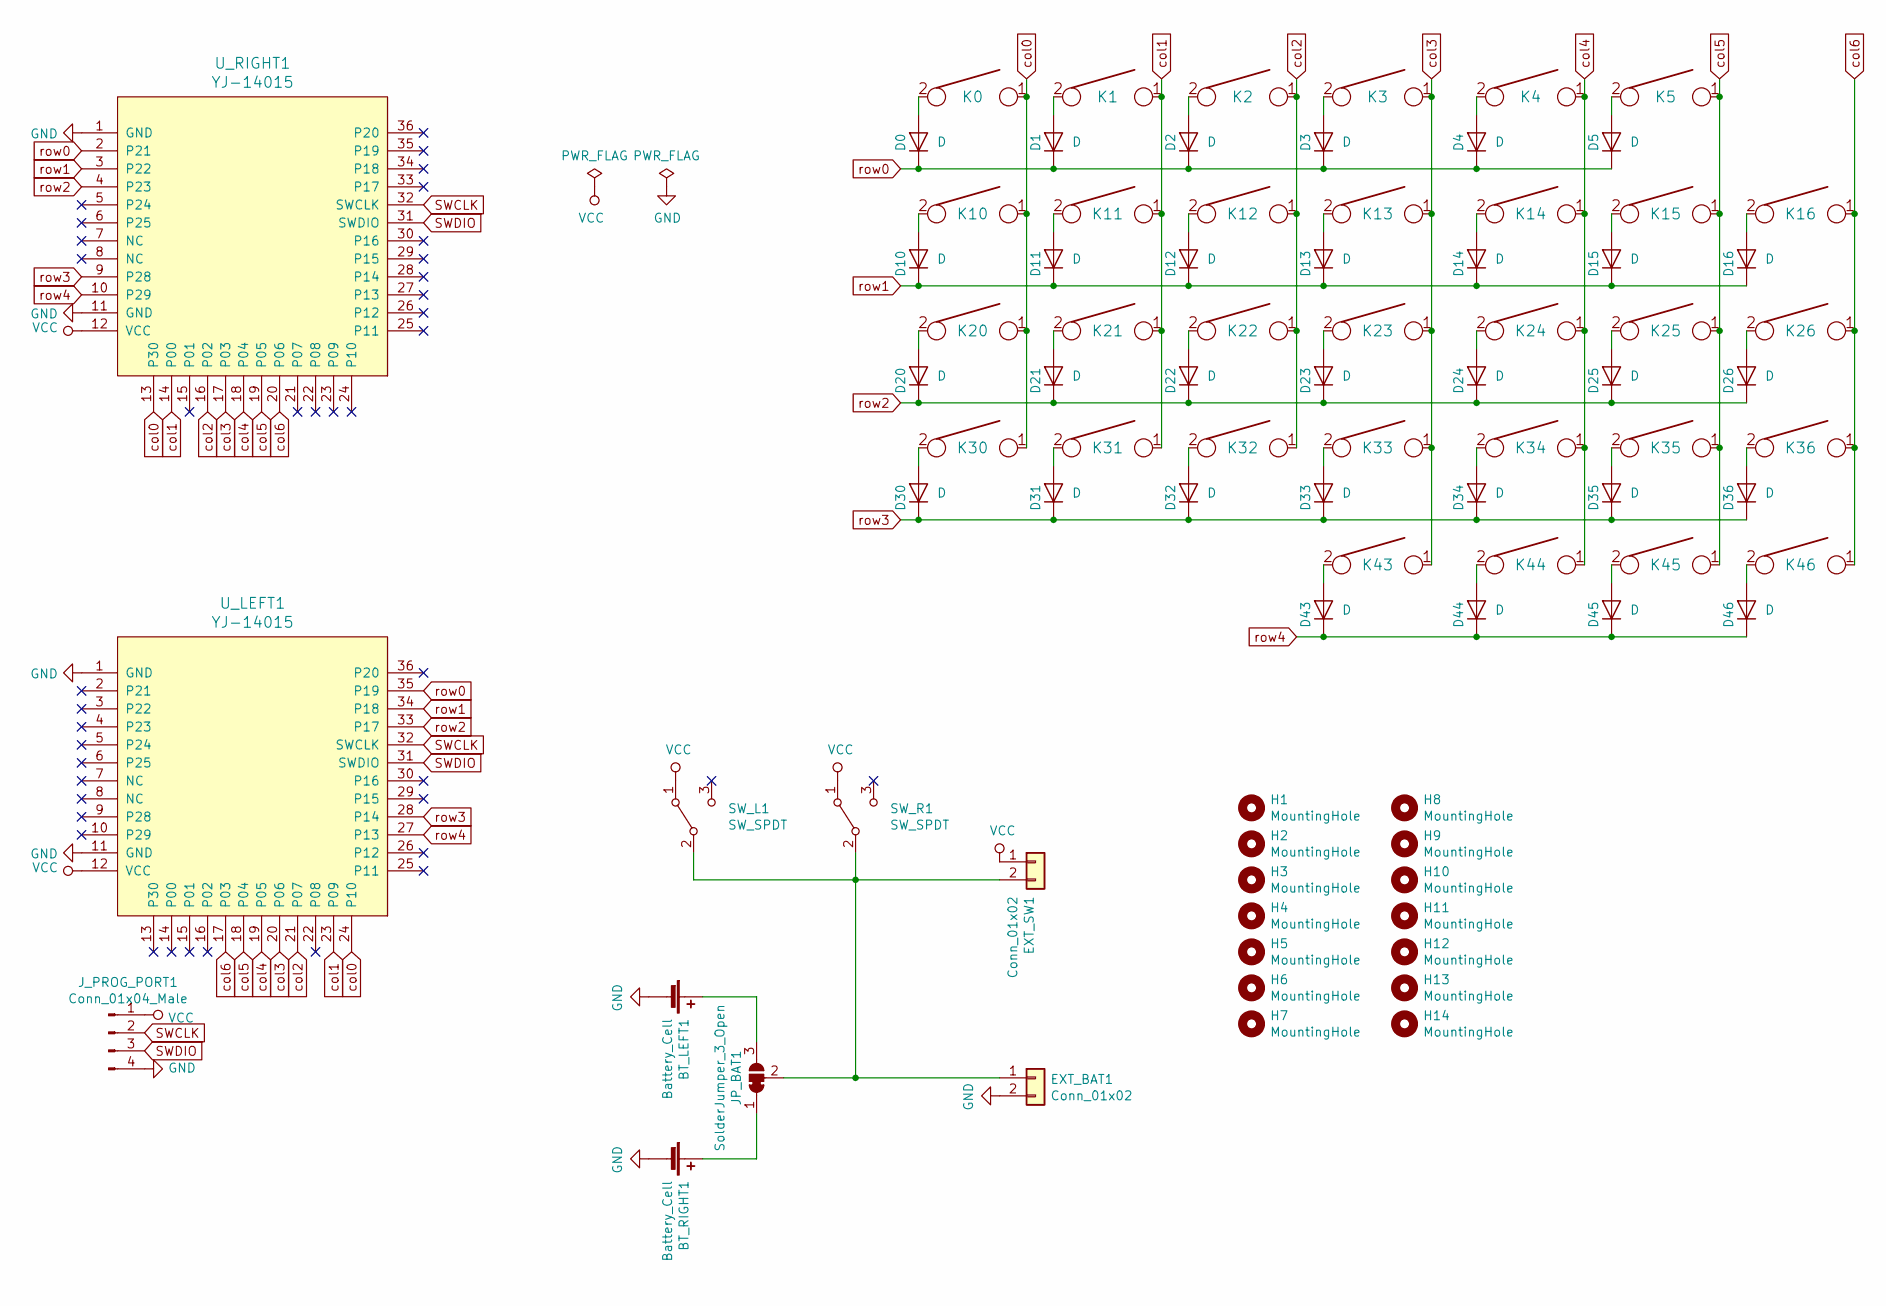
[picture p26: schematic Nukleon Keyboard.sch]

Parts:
BT_LEFT1: Battery_Cell; BatteryHolder_Keystone_3034_1x20mm_left
BT_RIGHT1: Battery_Cell; BatteryHolder_Keystone_3034_1x20mm_right
D0, D1, D2, D3, D4, D5, D10, D11, D12, D13, D14, D15, D16, D20, D21, D22, D23, D24, D25, D26, D30, D31, D32, D33, D34, D35, D36, D43, D44, D45, D46: D; D_SOD123_axial_both_sides
EXT_BAT1: Conn_01x02; PinHeader_1x02_P2.54mm_Horizontal_double_side
EXT_SW1: Conn_01x02; PinHeader_1x02_P2.54mm_Horizontal_double_side
H1, H2, H3, H4, H5, H9, H10, H12, H14: MountingHole; MountingHole_2.2mm_M2_ISO7380_Pad
H6, H7, H8, H11, H13: MountingHole; Thru_hole_for_M2_standoff_space
JP_BAT1: SolderJumper_3_Open; SolderJumper-3_P1.3mm_Open_RoundedPad1.0x1.5mm_NumberLabels
J_PROG_PORT1: Conn_01x04_Male; PinHeader_1x04_P2.54mm_Horizontal
K0, K1, K2, K3, K4, K5, K10, K11, K12, K13, K14, K15, K16, K20, K21, K22, K23, K24, K25, K26, K30, K31, K32, K33, K34, K35, K36: KEYSW; SW_Cherry_MX_1.00u_PCB_Hot_Swap_Optional
K43, K44, K45, K46: KEYSW; PG1350_socket_reversible_MX_Holtite
SW_L1: SW_SPDT; SW_SPDT_PCM12
SW_R1: SW_SPDT; SW_SPDT_PCM12
U_LEFT1: YJ-14015; MY-YJ-14015-Module
U_RIGHT1: YJ-14015; MY-YJ-14015-Module

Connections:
GND: BT_LEFT1.2 (-), BT_RIGHT1.2 (-), EXT_BAT1.2, J_PROG_PORT1.4, U_LEFT1.1 (GND), U_LEFT1.11 (GND), U_RIGHT1.1 (GND), U_RIGHT1.11 (GND)
unnamed: BT_LEFT1.1 (+), JP_BAT1.3 (B)
unnamed: BT_RIGHT1.1 (+), JP_BAT1.1 (A)
unnamed: D0.2 (A), K0.2
unnamed: D1.2 (A), K1.2
unnamed: D2.2 (A), K2.2
unnamed: D3.2 (A), K3.2
unnamed: D4.2 (A), K4.2
unnamed: D5.2 (A), K5.2
unnamed: D10.2 (A), K10.2
unnamed: D11.2 (A), K11.2
unnamed: D12.2 (A), K12.2
unnamed: D13.2 (A), K13.2
unnamed: D14.2 (A), K14.2
unnamed: D15.2 (A), K15.2
unnamed: D16.2 (A), K16.2
unnamed: D20.2 (A), K20.2
unnamed: D21.2 (A), K21.2
unnamed: D22.2 (A), K22.2
unnamed: D23.2 (A), K23.2
unnamed: D24.2 (A), K24.2
unnamed: D25.2 (A), K25.2
unnamed: D26.2 (A), K26.2
unnamed: D30.2 (A), K30.2
unnamed: D31.2 (A), K31.2
unnamed: D32.2 (A), K32.2
unnamed: D33.2 (A), K33.2
unnamed: D34.2 (A), K34.2
unnamed: D35.2 (A), K35.2
unnamed: D36.2 (A), K36.2
unnamed: D43.2 (A), K43.2
unnamed: D44.2 (A), K44.2
unnamed: D45.2 (A), K45.2
unnamed: D46.2 (A), K46.2
unnamed: EXT_BAT1.1, EXT_SW1.2, JP_BAT1.2 (C), SW_L1.2 (B), SW_R1.2 (B)
SWCLK: J_PROG_PORT1.2, U_LEFT1.32 (SWCLK), U_RIGHT1.32 (SWCLK)
SWDIO: J_PROG_PORT1.3, U_LEFT1.31 (SWDIO), U_RIGHT1.31 (SWDIO)
VCC: EXT_SW1.1, J_PROG_PORT1.1, SW_L1.1 (A), SW_R1.1 (A), U_LEFT1.12 (VCC), U_RIGHT1.12 (VCC)
col0: K0.1, K10.1, K20.1, K30.1, U_LEFT1.24 (P10), U_RIGHT1.13 (P30)
col1: K1.1, K11.1, K21.1, K31.1, U_LEFT1.23 (P09), U_RIGHT1.14 (P00)
col2: K2.1, K12.1, K22.1, K32.1, U_LEFT1.21 (P07), U_RIGHT1.16 (P02)
col3: K3.1, K13.1, K23.1, K33.1, K43.1, U_LEFT1.20 (P06), U_RIGHT1.17 (P03)
col4: K4.1, K14.1, K24.1, K34.1, K44.1, U_LEFT1.19 (P05), U_RIGHT1.18 (P04)
col5: K5.1, K15.1, K25.1, K35.1, K45.1, U_LEFT1.18 (P04), U_RIGHT1.19 (P05)
col6: K16.1, K26.1, K36.1, K46.1, U_LEFT1.17 (P03), U_RIGHT1.20 (P06)
row0: D0.1 (K), D1.1 (K), D2.1 (K), D3.1 (K), D4.1 (K), D5.1 (K), U_LEFT1.35 (P19), U_RIGHT1.2 (P21)
row1: D10.1 (K), D11.1 (K), D12.1 (K), D13.1 (K), D14.1 (K), D15.1 (K), D16.1 (K), U_LEFT1.34 (P18), U_RIGHT1.3 (P22)
row2: D20.1 (K), D21.1 (K), D22.1 (K), D23.1 (K), D24.1 (K), D25.1 (K), D26.1 (K), U_LEFT1.33 (P17), U_RIGHT1.4 (P23)
row3: D30.1 (K), D31.1 (K), D32.1 (K), D33.1 (K), D34.1 (K), D35.1 (K), D36.1 (K), U_LEFT1.28 (P14), U_RIGHT1.9 (P28)
row4: D43.1 (K), D44.1 (K), D45.1 (K), D46.1 (K), U_LEFT1.27 (P13), U_RIGHT1.10 (P29)

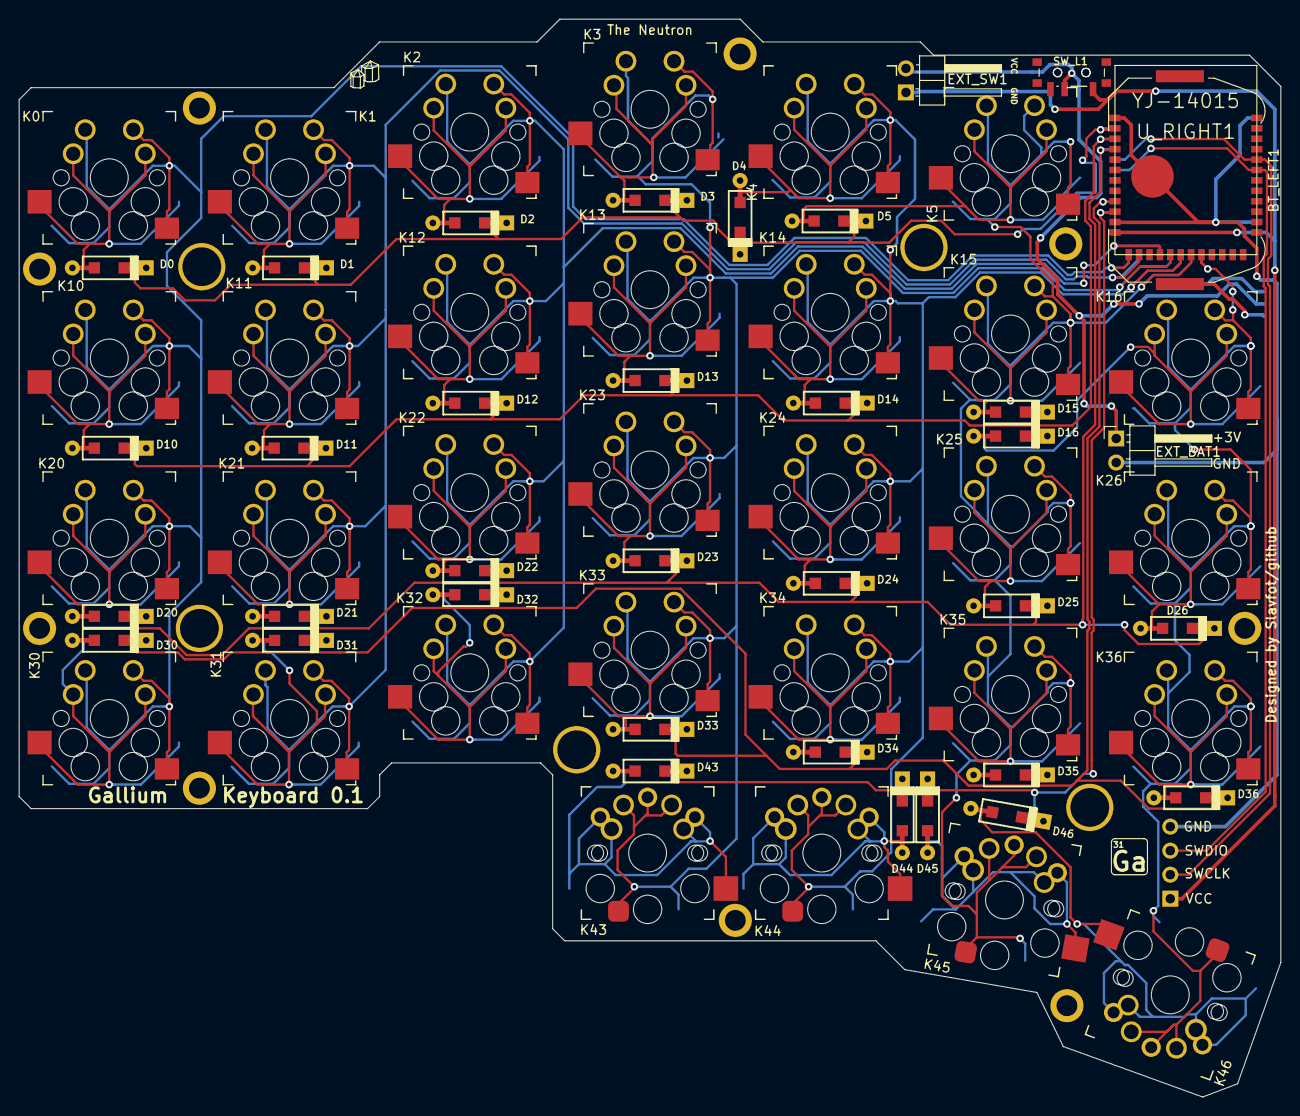
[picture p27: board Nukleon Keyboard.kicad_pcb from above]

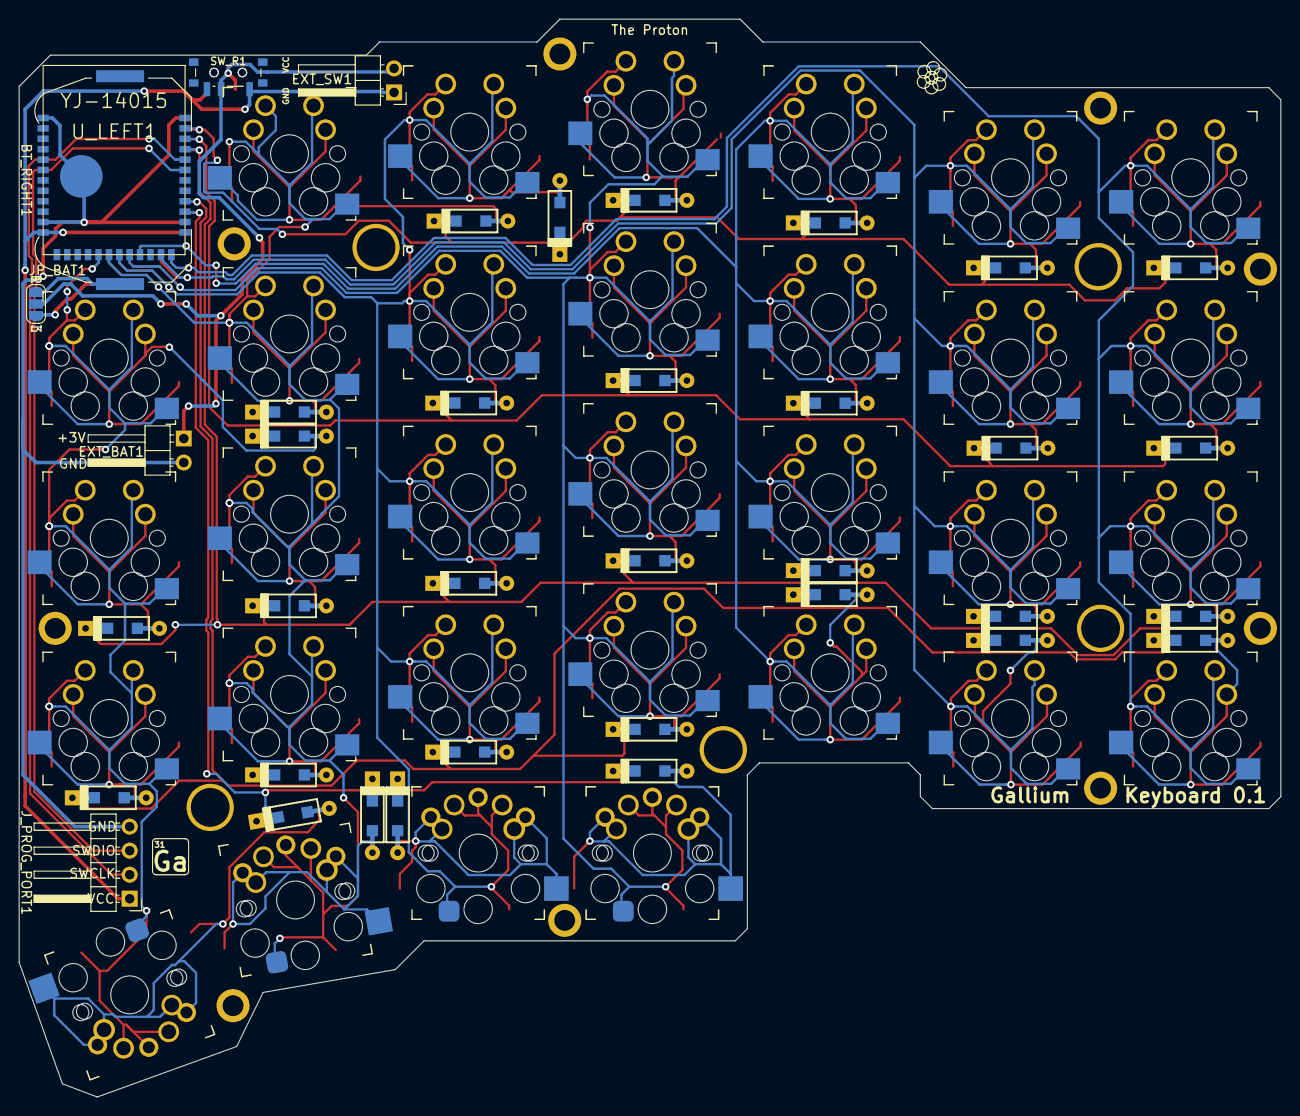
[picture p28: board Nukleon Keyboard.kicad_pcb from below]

Board: 2 copper layers, 133.3 x 113.9 mm, 86 parts (6 on the bottom side), 50 nets.

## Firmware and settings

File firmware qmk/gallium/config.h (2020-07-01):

/* Copyright 2020 Anton Scorénius
 * 
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
 * You should have received a copy of the GNU General Public License
 * along with this program.  If not, see <http://www.gnu.org/licenses/>.
 */

#pragma once

#include "config_common.h"

/* USB Device descriptor parameter */

#define VENDOR_ID       0xFEED
#define PRODUCT_ID      0x6060
#define DEVICE_VER      0x0001
#define MANUFACTURER    ASC
#define PRODUCT         Gallium Keyboard
#define DESCRIPTION     q.m.k. keyboard firmware for Gallium keyboard

/* key matrix size */
#define MATRIX_ROWS 5
#define MATRIX_COLS 14

/* define if matrix has ghost */
//#define MATRIX_HAS_GHOST

/* number of backlight levels */
//#define BACKLIGHT_LEVELS 3

#define ONESHOT_TIMEOUT 500
#define TAPPING_TERM 175

/*
 * Feature disable options
 *  These options are also useful to firmware size reduction.
 */

/* disable debug print */
//#define NO_DEBUG

/* disable print */
//#define NO_PRINT

/* disable action features */
//#define NO_ACTION_LAYER
//#define NO_ACTION_TAPPING
//#define NO_ACTION_ONESHOT
//#define NO_ACTION_MACRO
//#define NO_ACTION_FUNCTION

//UART settings for communication with the RF microcontroller
#define SERIAL_UART_BAUD 1000000
#define SERIAL_UART_DATA UDR1
#define SERIAL_UART_UBRR (F_CPU / (16UL * SERIAL_UART_BAUD) - 1)
#define SERIAL_UART_TXD_READY (UCSR1A & _BV(UDRE1))
#define SERIAL_UART_RXD_PRESENT (UCSR1A & _BV(RXC1))
#define SERIAL_UART_INIT() do { \
    	/* baud rate */ \
    	UBRR1L = SERIAL_UART_UBRR; \
    	/* baud rate */ \
    	UBRR1H = SERIAL_UART_UBRR >> 8; \
    	/* enable TX and RX */ \
    	UCSR1B = _BV(TXEN1) | _BV(RXEN1); \
    	/* 8-bit data */ \
    	UCSR1C = _BV(UCSZ11) | _BV(UCSZ10); \
  	} while(0)

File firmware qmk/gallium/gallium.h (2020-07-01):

#pragma once

#include "quantum.h"

#define red_led_off   PORTF |= (1<<5)
#define red_led_on    PORTF &= ~(1<<5)
#define blu_led_off   PORTF |= (1<<4)
#define blu_led_on    PORTF &= ~(1<<4)
#define grn_led_off   PORTD |= (1<<1)
#define grn_led_on    PORTD &= ~(1<<1)
#define wht_led_off   PORTD |= (1<<0)
#define wht_led_on    PORTD &= ~(1<<0)

#define set_led_off     red_led_off; grn_led_off; blu_led_off;	wht_led_off
#define set_led_red     red_led_on;  grn_led_off; blu_led_off;	wht_led_off
#define set_led_blue    red_led_off; grn_led_off; blu_led_on;	wht_led_off
#define set_led_green   red_led_off; grn_led_on;  blu_led_off;	wht_led_off
#define set_led_yellow  red_led_on;  grn_led_on;  blu_led_off;	wht_led_off
#define set_led_magenta red_led_on;  grn_led_off; blu_led_on;	wht_led_off
#define set_led_cyan    red_led_off; grn_led_on;  blu_led_on;	wht_led_off
#define set_led_white   red_led_off; grn_led_off; blu_led_off;	wht_led_on

// This a shortcut to help you visually see your layout.
// The first section contains all of the arguements
// The second converts the arguments into a two-dimensional array
#define LAYOUT( \
  k13, k12, k11, k10, k09, k08,                          k05, k04, k03, k02, k01, k00, \
  k27, k26, k25, k24, k23, k22, k07,                k06, k19, k18, k17, k16, k15, k14, \
  k41, k40, k39, k38, k37, k36, k21,                k20, k33, k32, k31, k30, k29, k28, \
  k55, k54, k53, k52, k51, k50, k35, k49,      k48, k34, k47, k46, k45, k44, k43, k42, \
  k69, k68, k67, k66,    k65,   k64, k63,      k62, k61,   k60,    k59, k58, k57, k56  \
) \
{ \
	{ k00, k01, k02, k03, k04, k05, k06, k07, k08, k09, k10, k11, k12, k13 }, \
	{ k14, k15, k16, k17, k18, k19, k20, k21, k22, k23, k24, k25, k26, k27 }, \
	{ k28, k29, k30, k31, k32, k33, k34, k35, k36, k37, k38, k39, k40, k41 }, \
	{ k42, k43, k44, k45, k46, k47, k48, k49, k50, k51, k52, k53, k54, k55 }, \
	{ k56, k57, k58, k59, k60, k61, k62, k63, k64, k65, k66, k67, k68, k69 }  \
}

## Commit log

2021-02-04 Updated Receiver Assembly
    Updated Receiver Assembly Order
2021-02-04 added kicad files
    added kicad files
    [Nukleon Keyboard-Dwgs_User.dxf, Nukleon Keyboard.kicad_pcb, Nukleon Keyboard.sch]
2021-02-04 Added STL
    Added STL for case revision 0.1
    Added plate file .dxf for revision 0.1
    [Gallium 0.1 Case Backplate .STL, Gallium 0.1 Case Backplate+Inner Frame combined.STL, Gallium 0.1 Case Inner Frame.STL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]

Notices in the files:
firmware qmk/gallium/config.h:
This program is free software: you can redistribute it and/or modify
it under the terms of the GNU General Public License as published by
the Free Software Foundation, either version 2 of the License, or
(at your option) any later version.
